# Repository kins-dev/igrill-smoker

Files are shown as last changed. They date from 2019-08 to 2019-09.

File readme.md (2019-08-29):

# Starting with Raspberry Pi Stretch 

<!-- markdownlint-disable MD036 -->
**&#x1F534; Note: You are 100% responsible for ensuring safe food practices are followed.**

**&#x1F534; Check and modify temperatures as appropriate**
<!-- markdownlint-enable MD036 -->

<!-- markdownlint-disable MD033 -->
<h2>Table of Contents</h2>
<!-- markdownlint-enable MD033 -->
<!-- markdownlint-disable MD039 -->
<!-- @import "[TOC]" {cmd="toc" depthFrom=2 depthTo=6 orderedList=false} -->

<!-- code_chunk_output -->

- [Problem Statement](#problem-statement)
- [Design](#design)
- [Equipment](#equipment)
- [Requirements](#requirements)
- [Installation](#installation)
- [Software Setup](#software-setup)
- [Using iGrill Mini](#using-igrill-mini)
- [Grill Setup](#grill-setup)
- [Running](#running)
- [Lighttpd Setup](#lighttpd-setup)
- [Project Notes](#project-notes)
- [iGrill Smoker Board Rev. *A](#igrill-smoker-board-rev-a)
  - [*A Board](#a-board)
  - [*A Notes](#a-notes)
  - [*A Parts](#a-parts)
- [iGrill Smoker Board Rev. *B](#igrill-smoker-board-rev-b)
  - [*B Board](#b-board)
  - [*B Notes](#b-notes)
  - [*B Parts](#b-parts)
- [iGrill Smoker Board Rev. *C](#igrill-smoker-board-rev-c)
  - [*C Board](#c-board)
  - [*C Notes](#c-notes)
  - [*C Parts](#c-parts)
- [iGrill Smoker Board Rev. *D](#igrill-smoker-board-rev-d)
  - [*D Notes](#d-notes)
  - [*D Parts](#d-parts)
- [iGrill Smoker Board Rev. *E](#igrill-smoker-board-rev-e)
  - [*E Notes](#e-notes)
  - [*E Parts](#e-parts)

<!-- /code_chunk_output -->

<!-- markdownlint-enable MD039 -->
## Problem Statement

Create a low cost smoking unit that can be controlled/monitored via the internet.

## Design

See the [design document](documentation/iGrill_smoker_design.md).

## Equipment

Prices as of June 10th, 2019.  Some items like the hotplates or skillet can be found at Goodwill instead.  Total cost (new) $287.96.  Every item can be used for more than one task.  Meat, wood chips, and extension cords not included.

- [Weber Grill](https://www.amazon.com/Weber-741001-Original-22-Inch-Charcoal/dp/B00004RALU/ref=sr_1_3) - $109
- [iGrill2](https://www.amazon.com/Weber-7203-iGrill-2-Thermometer/dp/B01MG2CNDL/ref=sr_1_3) - $64.99
- [Hotplate](https://www.amazon.com/Cuisine-ESB-300X-Maxi-Matic-Single-Electric/dp/B0006A2ZTS/ref=sr_1_70) - 2x @ $12.96
- [TP-Link Kasa](https://www.amazon.com/TP-Link-HS100-Required-Google-Assistant/dp/B0178IC734/ref=sr_1_4) - $14.69
- [Raspberry Pi](https://www.target.com/p/raspberry-pi-3-model-b-project-board/-/A-53349740) - $34.49
- [SD Card](https://www.amazon.com/Kingston-Digital-microSDHC-SDC4-8GBSP/dp/B0027CA7UW/ref=sr_1_11) - $3.99
- [Skillets](https://www.amazon.com/dp/B073Q8P6C8/ref=psdc_289821_t1_B00008GKDN) - 2x @ $10.93
- [8 inch rings](https://www.amazon.com/Ateco-14408-8-Inch-Stainless-Cutter/dp/B002A5BU5M/ref=pd_sbs_79_5/140-6446357-6003018) - 2x @ $6.51

## Requirements

You must have:

- Raspberry Pi 3
- TP-Link Kasa
- iGrill2 or iGrill3 (iGrill mini coming soon for time based smoking)

Optional items:

- LEDs with current limiting resistors
- Speaker with 3.5 mm stereo jack input

*Note: This has been tested using a Raspberry Pi B 3 with Raspian Stretch.  Your milage may vary.*

This guide assumes you've done the basic setup of network and updated the system on your Raspberry Pi.  Remember, you probably want to enable ssh access.  You must have your iGrill ready to complete the installation and setup.  This does require python 3 to be installed.

## Installation

Either download and run ```auto-install.sh``` from the installation directory or run the following commands:

```bash
git clone https://git.kins.dev/igrill-smoker
cd igrill-smoker/install
bash run-install.sh
```

After starting the ```run-install.sh``` script, you should turn on your iGrill v2.  Installation shouldn't take long and the device is needed for setup.

## Software Setup

Copy ```config/iGrill_config.example.ini``` to ```config/iGrill_config.ini```.  Update ```iGrill_config.ini``` with any system settings you want to change.

Here is what that file looks like:
<!-- TODO: add > at the end of this line, open MPE, and use shift enter to regenerate --
```bash {cmd hide modify_source}
echo -n \`\`\`ini
cat config/iGrill_config.example.ini
echo -n \`\`\`
```
<!---->

<!-- code_chunk_output -->

```ini
# Copyright (c) 2019:   Scott Atkins <scott@kins.dev>
#                       (https://git.kins.dev/igrill-smoker)
# License:              MIT License
#                       See the LICENSE file
[iGrill]
# can be Standard or Mini
Type=Standard

[Probes]
# For iGrill mini set food probe to 0 and smoke probe to 1

# Food probe must be set between 0 and 4, where 0 means the
# probe is disabled.  The left most probe is 1 and right most
# is 4 on the iGrill 2/3
#
# If you disable the food probe, you must use a stage that
# is iGrill mini compatible (see stage file) or disable stages
FoodProbe=1

# Smoke probe must be set between 1 and 4.  The left most probe
# is 1 and right most is 4 on the iGrill 2/3
SmokeProbe=4

[Logging]
LogLevel=INFO
LogFile=

[Kasa]
# Name of your plug in the Kasa app, case sensitive
Name=iGrill-smoker

[Smoking]
MaxTempChange=2
TempBandSize=7

# Can be the name of any file in the stages directory (excluding the .sh) or None
Food=brisket

# Only valid if Food=None
SmokeMid=225
InternalTarget=185

[Reporting]
# time in seconds between polls of the iGrill
# faster polling means more power use
PollTime=20

ResultsDirectory=/var/www/html
CSVFile=current.csv
StateFile=state.json
```

<!-- /code_chunk_output -->

Edit the chart.html file in the website_example directory to suit your needs and copy it to your ```/var/www/html``` directory.

## Using iGrill Mini

The iGrill mini has a single probe.  That means you can either monitor the smoke temperature or the food temperature.  Since this is controlling a plug for the smoke, you should not monitor the food temperature via the iGrill mini probe.  Follow the instructions in iGrill_config.example.ini for setting the probe values.

## Grill Setup

## Running

Start a smoking session by running:

```bash
./start_smoking.sh
```

## Lighttpd Setup

Secure your instance of lighttpd using the instructions at <https://github.com/galeone/letsencrypt-lighttpd/blob/master/renew.sh>.  You may want a wildcard certificate and you can find instructions via <https://asknetsec.com/generate-lets-encrypt-free-wildcard-certificate-using-certbot-ubuntu-16-04/>.  Check your SSL setup via <https://www.ssllabs.com/ssltest/index.html>.

Also, it may be a good idea to setup lighttpd such that ```*.csv```/```*.json``` is not cached.  Here's an example lighttpd config file:

```ruby
server.modules = (
        "mod_expire",
        "mod_access",
        "mod_alias",
        "mod_compress",
        "mod_redirect",
        "mod_setenv",
        "mod_dirlisting",
)

server.document-root                            = "/var/www/html"
server.upload-dirs                              = ( "/var/cache/lighttpd/uploads" )
server.errorlog                                 = "/var/log/lighttpd/error.log"
server.pid-file                                 = "/var/run/lighttpd.pid"
server.username                                 = "www-data"
server.groupname                                = "www-data"
server.port                                     = 80

index-file.names                                = ( "index.php", "index.html", "index.lighttpd.html" )
url.access-deny                                 = ( "~", ".inc" )
static-file.exclude-extensions                  = ( ".php", ".pl", ".fcgi" )

compress.cache-dir                              = "/var/cache/lighttpd/compress/"
compress.filetype                               = ( "application/javascript", "text/css", "text/html", "text/plain" )

# default listening port for IPv6 falls back to the IPv4 port
## Use ipv6 if available
#include_shell "/usr/share/lighttpd/use-ipv6.pl " + server.port
include_shell "/usr/share/lighttpd/create-mime.assign.pl"
include_shell "/usr/share/lighttpd/include-conf-enabled.pl"

# SSL Config
$SERVER["socket"] == ":443" {
        protocol                                = "https://"
        ssl.engine                              = "enable"
        ssl.ca-file                             = "/etc/lighttpd/fullchain.pem"
        ssl.pemfile                             = "/etc/lighttpd/wildcard.cert.pem"

        setenv.add-environment  = (
                "HTTPS"                         => "on"
        )

        setenv.add-response-header  = (
                # Allow cross domain access
                # Safari requires *
                "Access-Control-Allow-Origin"   => "*",

                # Used to identify the server based on headers
                "Server"                        => "Server name",

                # Set timeout for ssl access
                "Strict-Transport-Security"     => "max-age=15768000;"
        )

        # Mitigate BEAST attack:
        #
        # A stricter base cipher suite. For details see:
        # http://blog.ivanristic.com/2011/10/mitigating-the-beast-attack-on-tls.html
        ssl.cipher-list                         = "ECDHE-ECDSA-AES256-GCM-SHA384:ECDHE-RSA-AES256-GCM-SHA384:ECDHE-ECDSA-CHACHA20-POLY1305:ECDHE-RSA-CHACHA20-POLY1305:ECDHE-ECDSA-AES128-GCM-SHA256:ECDHE-RSA-AES128-GCM-SHA256:ECDHE-ECDSA-AES256-SHA384:ECDHE-RSA-AES256-SHA384:ECDHE-ECDSA-AES128-SHA256:ECDHE-RSA-AES128-SHA256"

        # Make the server prefer the order of the server side cipher suite instead of the client suite.
        # This is necessary to mitigate the BEAST attack (unless you disable all non RC4 algorithms).
        # This option is enabled by default, but only used if ssl.cipher-list is set.
        ssl.honor-cipher-order                  = "enable"

        # Mitigate CVE-2009-3555 by disabling client triggered renegotiation
        # This is enabled by default.
        ssl.disable-client-renegotiation        = "enable"
        ssl.ec-curve                            = "secp384r1"
        ssl.use-compression                     = "disable"

        # Disable SSLv2 because is insecure
        ssl.use-sslv2                           = "disable"

        # Disable SSLv3 (can break compatibility with some old browser) /cares
        ssl.use-sslv3                           = "disable"
}

# Prevent caching of json/csv files
$HTTP["url"] =~ "/.*\.(json|csv)$" {
        expire.url = (
                ""                              => "access 0 seconds",
        )
}
```

## Project Notes

1.3 Uses TP-Link Kasa for power control.  1.4 includes a brand new power control board that plugs into the Raspberry Pi which will allow much more fine grain control of the smoker temperature.

This is necessary because the relay in the TP-Link won't handle the number of on/off cycles required.  Instead a solid state relay is used.  A word of caution, this is not UL rated or certified.  If you don't know which end of the soldering iron to hold, then you probably should just stick with 1.3.

The TP-Link Kasa plug will still be used as a failsafe device in the system.

## iGrill Smoker Board Rev. *A

### *A Board

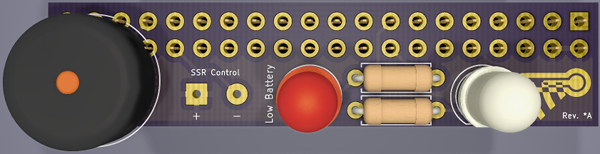
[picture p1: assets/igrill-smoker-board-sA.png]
Board Rev. *A


This board has a buzzer, two LEDs and connection points for the solid state relay.  It sits off the edge of the Raspberry Pi GPIOs.

### *A Notes

This board should not be used.

Features

- Two LEDs
- Buzzer
- Small design

Defects

- The spacing for the resistors is off
- Hard to hand solder
- Hangs off the board the wrong way
- Red LED stays on due to leakage current
- Leakage current to the SSR

### *A Parts

- Header (2x20): [DigiKey](https://www.digikey.com/product-detail/en/sullins-connector-solutions/SFH11-PBPC-D20-ST-BK/S9200-ND/1990093) $1.94
- LED (Green): [DigiKey](https://www.digikey.com/product-detail/en/lite-on-inc/LTL-4233/160-1130-ND/217580) $0.36
- LED (Red): [DigiKey](https://www.digikey.com/product-detail/en/wurth-electronics-inc/151051RS11000/732-5016-ND/4490012) $0.15
- Resistors (100 ohm x2): [DigiKey](https://www.digikey.com/product-detail/en/stackpole-electronics-inc/CF14JT100R/CF14JT100RCT-ND/1830327) $0.10
- Buzzer: [DigiKey](https://www.digikey.com/product-detail/en/tdk-corporation/PS1240P02BT/445-2525-1-ND/935930) $0.68

## iGrill Smoker Board Rev. *B

### *B Board

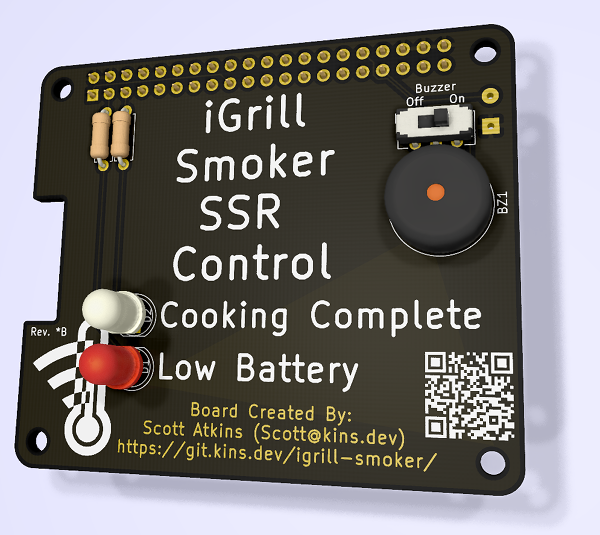
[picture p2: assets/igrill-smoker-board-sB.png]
Board Rev. *B


This board has a buzzer, two LEDs and connection points for the solid state relay.  It sits on the Raspberry Pi GPIOs.

### *B Notes

This board should not be used.

New Features

- Sits over the Pi with mounting holes
- Board auto detect works
- Buzzer switch

Defects

- The spacing for the resistors is off
- The QR code doesn't always read correctly
- The solder mask makes it hard to read the @ symbol
- Red LED stays on due to leakage current
- Buzzer makes a sound when it shouldn't
- Leakage current to the SSR

### *B Parts

- Header (2x20): [DigiKey](https://www.digikey.com/product-detail/en/sullins-connector-solutions/SFH11-PBPC-D20-ST-BK/S9200-ND/1990093) $1.94
- LED (Green): [DigiKey](https://www.digikey.com/product-detail/en/lite-on-inc/LTL-4233/160-1130-ND/217580) $0.36
- LED (Red): [DigiKey](https://www.digikey.com/product-detail/en/wurth-electronics-inc/151051RS11000/732-5016-ND/4490012) $0.15
- Resistors (100 ohm x2): [DigiKey](https://www.digikey.com/product-detail/en/stackpole-electronics-inc/CF14JT100R/CF14JT100RCT-ND/1830327) $0.10
- Buzzer: [DigiKey](https://www.digikey.com/product-detail/en/tdk-corporation/PS1240P02BT/445-2525-1-ND/935930) $0.68
- Switch: [DigiKey](https://www.digikey.com/product-detail/en/c-k-components/JS202011CQN/401-2001-ND/1640097) $0.43

## iGrill Smoker Board Rev. *C

### *C Board

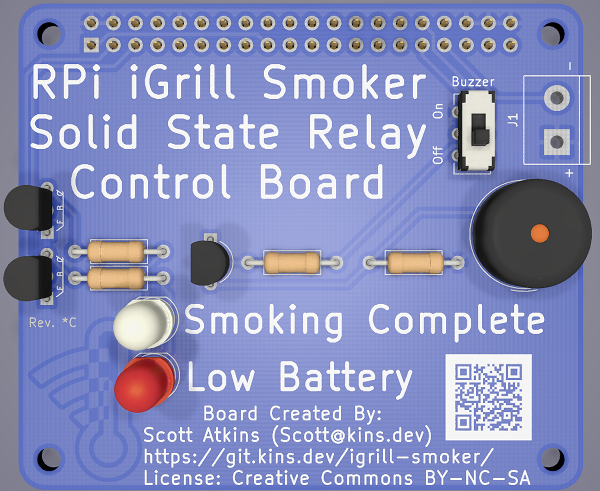
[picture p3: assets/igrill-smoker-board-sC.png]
Board Rev. *C


This board has a buzzer, two LEDs and a terminal block for the solid state relay.  It sits on the Raspberry Pi GPIOs.

### *C Notes

This board is currently in production and has not been tested.

New Features

- NPN transistors to remove leakage

Fixes

- QR Code
- Resistor spacing
- Solder mask changed to silk screen for fine pitch
- Using suggested design for the buzzer

Defects

- Leakage current to the SSR
- Missing resistors on NPN transistor base (good design practice)

### *C Parts

- Header (2x20): [DigiKey](https://www.digikey.com/product-detail/en/sullins-connector-solutions/SFH11-PBPC-D20-ST-BK/S9200-ND/1990093) $1.94
- LED (Green): [DigiKey](https://www.digikey.com/product-detail/en/lite-on-inc/LTL-4233/160-1130-ND/217580) $0.36
- LED (Red): [DigiKey](https://www.digikey.com/product-detail/en/wurth-electronics-inc/151051RS11000/732-5016-ND/4490012) $0.15
- Resistors (100 ohm x3): [DigiKey](https://www.digikey.com/product-detail/en/stackpole-electronics-inc/CF14JT100R/CF14JT100RCT-ND/1830327) $0.10
- Buzzer: [DigiKey](https://www.digikey.com/product-detail/en/tdk-corporation/PS1240P02BT/445-2525-1-ND/935930) $0.68
- Switch: [DigiKey](https://www.digikey.com/product-detail/en/c-k-components/JS202011CQN/401-2001-ND/1640097) $0.43
- Transistors (NPN x3): [DigiKey](https://www.digikey.com/product-detail/en/micro-commercial-co/2N3904-AP/2N3904-APCT-ND/950591) $0.19

## iGrill Smoker Board Rev. *D

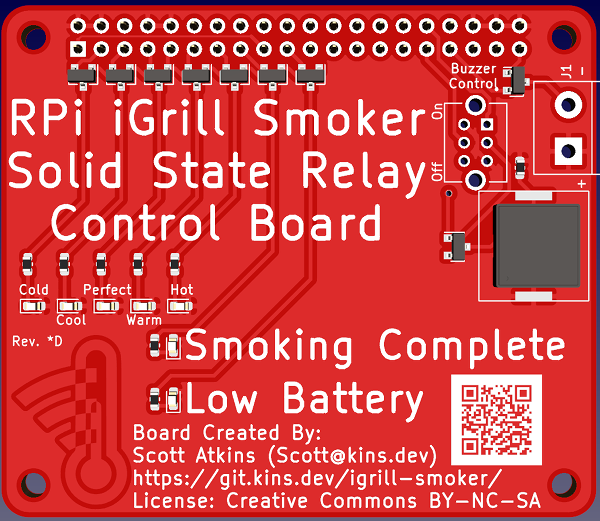
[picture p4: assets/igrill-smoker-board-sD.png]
Board Rev. *D


This board has a buzzer, seven LEDs and connection points for the solid state relay.  It sits on the Raspberry Pi GPIOs.

### *D Notes

The boards back from production are bad

New Features

- Five new LEDs for temperature monitoring
- Surface mount parts
- Mosfet transistors so a resistor is no longer needed
- Transistor to prevent SSR leakage
- Cheaper parts

Defects

- Silk screen issue
- QR Code issue (too small, inverted on back)
- Transistors wired backwards

### *D Parts

TODO: Add part list

## iGrill Smoker Board Rev. *E

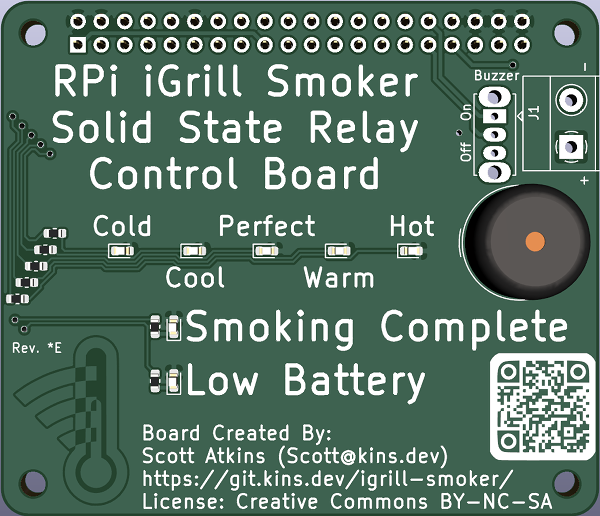
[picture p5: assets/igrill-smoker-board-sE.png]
Board Rev. *E


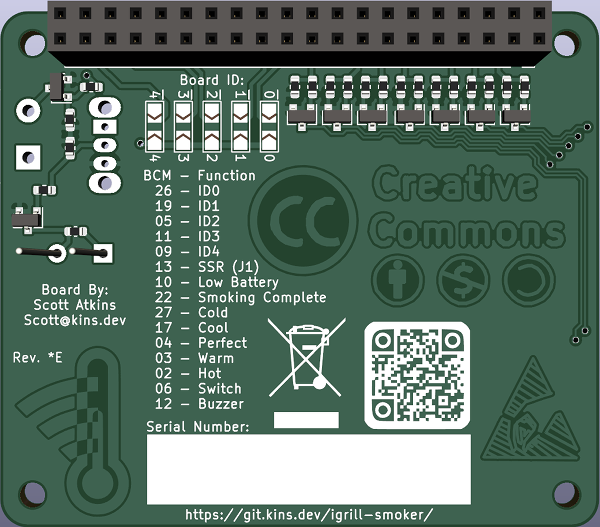
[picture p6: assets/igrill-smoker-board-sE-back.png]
Board Rev. *E back


This board has a buzzer, seven LEDs and connection points for the solid state relay.  It sits on the Raspberry Pi GPIOs.  It also has jumpers for a board id number

### *E Notes

This board is not yet in production and has not been tested.

New Features

- New QR code
- Pull down resistors for all transistors

Defects

- None found yet

### *E Parts

TODO: Add part list

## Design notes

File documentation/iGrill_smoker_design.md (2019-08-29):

# iGrill Smoker Design

Copyright &copy; 2019 Scott Atkins
<!-- markdownlint-disable MD033 -->
<h2>Table of Contents</h2>
<!-- markdownlint-enable MD033 -->
<!-- markdownlint-disable MD007 -->
<!-- markdownlint-disable MD010 -->
<!-- markdownlint-disable MD039 -->
<!-- @import "[TOC]" {cmd="toc" depthFrom=2 depthTo=6 orderedList=false} -->

<!-- code_chunk_output -->

- [Introduction](#introduction)
- [Sources](#sources)
- [Files](#files)
  - [Bash](#bash)
  - [Python](#python)
  - [INI](#ini)
  - [JSON](#json)
  - [CSV](#csv)
- [File relation graph](#file-relation-graph)
  - [/start_smoking.sh](#start_smokingsh)
  - [/scripts/config.sh](#scriptsconfigsh)
  - [/scripts/monitor.py](#scriptsmonitorpy)
  - [/scripts/data.sh](#scriptsdatash)
- [Configuration](#configuration)
  - [INI File](#ini-file)
- [How to Generate a Smoke Schedule](#how-to-generate-a-smoke-schedule)

<!-- /code_chunk_output -->
<!-- markdownlint-enable MD007 -->
<!-- markdownlint-enable MD010 -->
<!-- markdownlint-enable MD039 -->
## Introduction

There are a lot of moving parts in this project, so this is an attempt to document those parts and how they interact.  Additionally this a moving target, so some information can be out of date.

## Sources

Like most projects this has come from a number of different sources.

- [Github iGrill](https://github.com/kvantetore/igrill)
- [Bash ini Parser](https://github.com/rudimeier/bash_ini_parser)
- [Path helper](https://stackoverflow.com/questions/59895/get-the-source-directory-of-a-bash-script-from-within-the-script-itself)
- [Highcharts](https://www.highcharts.com/)
- [tplink-smarthome-api](https://www.npmjs.com/package/tplink-smarthome-api)

## Files

This is an attempt to document all the files in the project.  Relations between files is shown [below](#file-relation-graph).

### Bash

- **[igrill-smoker/start_smoking.sh](../start_smoking.sh)** - The main script to start a smoking session.
  - Loads [paths.sh](../scripts/utils/paths.sh)
  - Loads [leds.sh](../scripts/utils/leds.sh)
  - Loads [kasa.sh](../scripts/utils/kasa.sh)
  - Loads [limits.sh](../scripts/utils/limits.sh)
  - Loads [config.sh](../scripts/config.sh)
  - Cleans up after the last run
  - Resets the limits
  - Resets the LEDs
  - Finds iGrill device if needed
  - Creates list of CSV files
  - Creates new CSV file and links it to current.csv
  - Stats [scripts/py_utils/kasa_daemon.py](../scripts/py_utils/kasa_daemon.py) to control the plug state
  - Resets the BT device on the Raspberry Pi
  - Calls [scripts/monitor.py](../scripts/monitor.py) to capture data over bluetooth
  - On Exit
    - Uses [scripts/py_utils/kasa_client.py](../scripts/py_utils/kasa_client.py) to stop [scripts/py_utils/kasa_daemon.py](../scripts/py_utils/kasa_daemon.py)
    - Cleans up run files
    - Resets the LEDs
- **[igrill-smoker/scripts/config.sh](../scripts/config.sh)** - Loads configuration
  - Loads [read_ini.sh](../scripts/utils/read_ini.sh)
  - Loads [defaults.sh](../scripts/utils/defaults.sh)
  - Loads [food script](../config/stage/)
- **[igrill-smoker/scripts/data.sh](../scripts/data.sh)** - Handles temperature data
  - Loads [paths.sh](../scripts/utils/paths.sh)
  - Loads [config.sh](../scripts/config.sh)
  - Determines if it is time to load the next stage
    - If so writes stage.sh and reloads [config.sh](../scripts/config.sh)
  - Reads last_temp.sh
  - Adjusts LEDs based on stage, temperature, and battery
  - Plays sounds based on stage, temperature, and battery
  - Sets the plug state based on history and current temperature
  - Writes state.json
  - Writes last_temp.sh
  - Writes data to current.csv
  - Calls to [scripts/pygrill/kasa/kasa_client.py](../scripts/pygrill/kasa/kasa_client.py) to get the plug state
  - Calls to [scripts/pygrill/board/ssrc_client.py](../scripts/pygrill/board/ssrc_client.py) to adjust the solid state relay
  - Calls to [scripts/pygrill/board/buzzer_client.py](../scripts/pygrill/board/buzzer_client.py) to sound alarms
  - Calls to [scripts/pygrill/board/leds.py](../scripts/pygrill/board/leds.py) to set the LEDs
- **[igrill-smoker/scripts/utils/bt.sh](../scripts/utils/bt.sh)** - Bluetooth functions
  - **BtReset** - Resets Bluetooth
- **[igrill-smoker/scripts/utils/create_vars.sh](../scripts/utils/create_vars.sh)** - Setup default values
  - Reads iGrill_config.example.ini
  - Creates default.sh
- **[igrill-smoker/scripts/utils/defaults.sh](../scripts/utils/defaults.sh)** - Config default values if iGrill_config.ini does not exist
- **[igrill-smoker/scripts/utils/gen_json.sh](../scripts/utils/gen_json.sh)** - Creates JSON file for Website
  - Loads [paths.sh](../scripts/utils/paths.sh)
  - Finds all CSV files that match the date format
  - Writes a JSON file with the list of files
- **[igrill-smoker/scripts/utils/get_mac.sh](../scripts/utils/get_mac.sh)** - Creates mac_config.py based on iGrill Bluetooth address
  - Loads [bt.sh](../scripts/utils/bt.sh)
  - Calls BtReset
  - Starts a scan for iGrill
    - Scan is killed when iGrill is found
  - Writes mac_config.py
  - Calls BtReset
- **[igrill-smoker/scripts/utils/limits.sh](../scripts/utils/limits.sh)** - Sets upper and lower limits for the iGrill
  - Loads [paths.sh](../scripts/utils/paths.sh)
  - Reset limits - Sets limits for all 4 probes to be -32768 to 32767
  - SetLimits - Sets limits for a particular probe
  - PrintLimits - Output set limits in an INI format
  - WriteLimits - Uses PrintLimits to write to a file
- **[igrill-smoker/scripts/utils/paths.sh](../scripts/utils/paths.sh)** - Sets up standard path variables
- **[igrill-smoker/scripts/utils/read_ini.sh](../scripts/utils/read_ini.sh)** - Reads ini file
  - read_ini - Reads the specified file and sets variables
- **igrill-smoker/run/stage.sh** - Tracks the current cooking stage
- **igrill-smoker/run/last_temp.sh** - Tracks the last temperature
- **[igrill-smoker/tests/board/board_checkout.sh](../tests/board/board_checkout.sh)** - Runs through a set of tests to check the board is functioning properly
  - LEDs
  - Buzzer

### Python

- **[igrill-smoker/scripts/pygrill/bt_monitor.py](../scripts/pygrill/bt_monitor.py)** - Top level python script
  - Loads the configuration
  - Formats the results
  - Calls [scripts/data.sh](../scripts/data.sh) with the temperature data
- **[igrill-smoker/scripts/pygrill/bluetooth/igrill.py](../scripts/pygrill/bluetooth/igrill.py)** - Interface to iGrill
  - Performs handshake
  - Grabs temperature/battery data
  - Sets probe limits
- **[igrill-smoker/scripts/pygrill/common/local_logging.py](../scripts/pygrill/common/local_logging.py)** - Sets up logging
  - Report specific log level
  - Redirects to file if specified
- **[igrill-smoker/scripts/pygrill/common/constant.py](../scripts/pygrill/common/constant.py)** - Various constants
- **[igrill-smoker/scripts/pygrill/board/board.py](../scripts/pygrill/board/board.py)** - Detects the board type
  - Cannot detect **, *A or *D.1
- **[igrill-smoker/scripts/pygrill/board/buzzer_daemon.py](../scripts/pygrill/board/buzzer_daemon.py)** - Controls the buzzer
  - plays different sounds for smoking complete and low battery
- **[igrill-smoker/scripts/pygrill/board/buzzer_client.py](../scripts/pygrill/board/buzzer_client.py)** - Passes commands to the daemon
  - done or low_battery for those tones
  - Tells the daemon to exit
- **[igrill-smoker/scripts/pygrill/kasa/kasa_daemon.py](../scripts/pygrill/kasa/kasa_daemon.py)** - Controls kasa hardware
  - Find plug by name
  - Return plug status
  - Sets countdown timer for 10 minutes when turning the plug on
- **[igrill-smoker/scripts/pygrill/kasa/kasa_client.py](../scripts/pygrill/kasa/kasa_client.py)** - Passes commands to the daemon
  - Turn plug on and off
  - Return plug status
  - Tells the daemon to exit
- **[igrill-smoker/scripts/pygrill/board/ssrc_daemon.py](../scripts/pygrill/board/ssrc_daemon.py)** - Controls solid state relay
  - Minimum is 30% max is 85%
  - Step up by 5% or 0.25%
  - Step down by 1% or 20%
  - Sets countdown timer for 10 minutes
  - On exit, kill Kasa daemon
- **[igrill-smoker/scripts/pygrill/board/ssrc_client.py](../scripts/pygrill/board/ssrc_client.py)** - Passes commands to the daemon
  - Turn up or down, a large or small amount
  - Leave everything the same, but reset the countdown
  - Tells the daemon to exit
- **[igrill-smoker/scripts/pygrill/board/leds.py](../scripts/pygrill/board/leds.py)** - Controls LEDs
  - Sets smoking complete or low battery
  - Sets temperature state:
    - Cold: low outside of band
    - Cool: low in band
    - Perfect: at target temperature
    - Warm: high in band
    - Hot: high out of band
- **igrill-smoker/scripts/pygrill/config/mac_config.py** - Mac address for the iGrill

### INI

- **[iGrill_config.ini](../config/iGrill_config.example.ini)** - Main configuration
- **limits.ini** - iGrill upper and lower limits for alarm

### JSON

- **state.json** - Current state of the smoking for website processing
- **items.json** - A list of csv files which can put into highcharts

### CSV

- **current.csv** - The current data set

## File relation graph

This is broken down into multiple graphs so it is easier to follow.

- Dotted lines are file reads/writes
- Bold lines are system calls to execute a script
- Normal lines are standard includes

### /start_smoking.sh

start_smoking

### /scripts/config.sh

config

### /scripts/monitor.py

monitor

### /scripts/data.sh

data

## Configuration

### INI File

The ini file is a one place for the user to configure this project.

<!-- NOTE: Add > at the end of this line and open markdown preview enhanced window.  Use shift enter to regenerate. --
```bash {cmd hide modify_source}
echo -n \`\`\`ini
cat ../config/iGrill_config.example.ini
```
<!-- -->
<!-- code_chunk_output -->

```ini
# Copyright (c) 2019:   Scott Atkins <scott@kins.dev>
#                       (https://git.kins.dev/igrill-smoker)
# License:              MIT License
#                       See the LICENSE file
[iGrill]
# can be Standard or Mini
Type=Standard

[Probes]
# For iGrill mini set food probe to 0 and smoke probe to 1

# Food probe must be set between 0 and 4, where 0 means the
# probe is disabled.  The left most probe is 1 and right most
# is 4 on the iGrill 2/3
#
# If you disable the food probe, you must use a stage that
# is iGrill mini compatible (see stage file) or disable stages
FoodProbe=1

# Smoke probe must be set between 1 and 4.  The left most probe
# is 1 and right most is 4 on the iGrill 2/3
SmokeProbe=4

[Logging]
LogLevel=INFO
LogFile=

[Kasa]
# Name of your plug in the Kasa app, case sensitive
Name=iGrill-smoker

[Smoking]
MaxTempChange=2
TempBandSize=7

# Can be the name of any file in the stages directory (excluding the .sh) or None
Food=brisket

# Only valid if Food=None
SmokeMid=225
InternalTarget=185

# Used to specify the solid state relay board
[SSR]
# Possible values:
#  **, *A, *B, *C, *D, *D.1, *E, Auto, None
Board=Auto

[Reporting]
# time in seconds between polls of the iGrill
# faster polling means more power use
PollTime=20

ResultsDirectory=/var/www/html
CSVFile=current.csv
StateFile=state.json

```
<!-- /code_chunk_output -->

## How to Generate a Smoke Schedule

Easiest way is to copy then edit an existing schedule.  Examples and variable description is below.

Here is what **[igrill-smoker/config/stages/brisket.py](../config/stages/brisket.py)** looks like:
<!-- NOTE: Add > at the end of this line and open markdown preview enhanced window.  Use shift enter to regenerate. --
```bash {cmd hide modify_source}
echo \`\`\`bash
cat ../config/stages/brisket.sh
echo ""
echo -n \`\`\`
```
<!-- -->
<!-- code_chunk_output -->

```bash
#!/bin/bash
# Copyright (c) 2019:   Scott Atkins <scott@kins.dev>
#                       (https://git.kins.dev/igrill-smoker)
# License:              MIT License
#                       See the LICENSE file
# Defining variables for other scripts
# shellcheck disable=2034
true
# shellcheck disable=2086
set -$-ue${DEBUG+xv}

MINI_COMPATIBLE=false

# Note: for this to work. Internal temp must be increased at each stage
# the system will go to the next stage when the food hits the designated
# internal temp

case "$STAGE" in
    1)
        # Warmup stage, keep plate at a cooler temp and limit temp rise
        STAGE_NAME="Warmup"
        SMOKE_MID=180
        MAX_TEMP_CHANGE=2
        INTERNAL_TEMP=70
    ;;
    2)
        # Smoke stage, keep plate at cooler temp, but allow bigger temp rise
        STAGE_NAME="Smoke"
        SMOKE_MID=180
        MAX_TEMP_CHANGE=2
        INTERNAL_TEMP=120
    ;;
    3)
        # Cook stage, move hotplate to higher temp, allow bigger temp rise
        STAGE_NAME="Cook"
        SMOKE_MID=225
        MAX_TEMP_CHANGE=2
        INTERNAL_TEMP=170
    ;;
    4)
        # Braise stage, move hotplate to higher temp, allow bigger temp rise
        STAGE_NAME="Braise"
        SMOKE_MID=225
        MAX_TEMP_CHANGE=2
        INTERNAL_TEMP=185
    ;;
    5|6)
        # Keep warm stage, move hotplate to higher temp, allow bigger temp rise
        STAGE_NAME="Keep warm"
        SMOKE_MID=160
        MAX_TEMP_CHANGE=2
        INTERNAL_TEMP=190
        # signal we're done
        FD_DONE=1
        # Stay in this stage
        STAGE=5
    ;;
    *)
        echo "error: unknown stage"
        exit 1
    ;;
esac
```

<!-- /code_chunk_output -->

- ```$STAGE``` - Current stage as an integer
  - Must start at 1
  - Case statement for the last stage (5 in the example) must also include last stage + 1 (eg. ```5|6```)
  - Last stage must set ```$STAGE``` to the last stage again in case it was incremented (eg. ```STAGE=5```)
- ```$STAGE_NAME``` - Name to show on the webpage for this stage
- ```$INTERNAL_TEMP``` - Target food temperature for this stage
  - Should be monotonically increasing for every stage except the last one
  - Use of ```$INTERNAL_TEMP``` means ```$MINI_COMPATIBLE``` should be false
- ```$SMOKE_MID``` - Temperature the smoke should be kept at
- ```$FD_DONE```- The value ```1``` indicates the food is done (set on the last stage)
- ```$MAX_TEMP_CHANGE``` - Maximum change over a time period.  Should be 2-4

Here is what **[igrill-smoker/config/stages/baby-back-ribs.py](../config/stages/baby-back-ribs.py)** looks like:

<!-- NOTE: Add > at the end of this line and open markdown preview enhanced window.  Use shift enter to regenerate. --
```bash {cmd hide modify_source}
echo \`\`\`bash
cat ../config/stages/baby-back-ribs.sh
echo ""
echo -n \`\`\`
```

<!-- code_chunk_output -->

```bash
#!/bin/bash
# Copyright (c) 2019:   Scott Atkins <scott@kins.dev>
#                       (https://git.kins.dev/igrill-smoker)
# License:              MIT License
#                       See the LICENSE file
# Defining variables for other scripts
# shellcheck disable=2034
true
# shellcheck disable=2086
set -$-ue${DEBUG+xv}

MINI_COMPATIBLE=true

case "$STAGE" in
    1)
        # Warmup stage, keep plate at a cooler temp
        STAGE_NAME="Warmup"
        SMOKE_MID=180
        MAX_TEMP_CHANGE=2
        TIME=15
    ;;
    2)
        # Smoke stage, keep plate at cooler temp
        STAGE_NAME="Smoke"
        SMOKE_MID=180
        MAX_TEMP_CHANGE=2
        TIME=180
    ;;
    3)
        # Cook stage, move hotplate to higher temp
        STAGE_NAME="Cook"
        SMOKE_MID=225
        MAX_TEMP_CHANGE=2
        TIME=120
    ;;
    4)
        # Sauce stage
        STAGE_NAME="Sauce"
        SMOKE_MID=225
        MAX_TEMP_CHANGE=2
        TIME=60
    ;;
    5|6)
        # Keep warm stage, move hotplate to lower temp
        STAGE_NAME="Keep warm"
        SMOKE_MID=165
        MAX_TEMP_CHANGE=2
        TIME=100
        # signal we're done
        FD_DONE=1
        # Stay in this stage
        STAGE=5
    ;;
    *)
        echo "error: unknown stage"
        exit 1
    ;;
esac
```

<!-- /code_chunk_output -->

This is iGrill mini compatible and uses the time instead of food temperature

- ```$TIME``` - Minutes to stay in this stage

Both ```$TIME``` and ```$INTERNAL_TEMP``` can be used in a stage, first event to occur moves the system to the next stage.

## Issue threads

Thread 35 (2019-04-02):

Fail in a Safe Way

kins-dev, 2019-04-02:
Turn off the plug if there's no process running.

kins-dev, 2019-04-02:
When turning the plug on, set a timer for run time:
```bash
tplink-smarthome-api send $IP '{"count_down":{"delete_all_rules":{}}}}'
tplink-smarthome-api send $IP '{"count_down":{"add_rule":{"enable":1,"delay":300,"act":0,"name":"turn of"}}}'
```

Closed 2019-04-03.

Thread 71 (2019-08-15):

SSRC Unittests

kins-dev, 2019-08-15:
Solid state relay control needs unittests.  Should use python mock to check that it is called with the correct numbers.

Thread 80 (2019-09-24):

Smoker is Too Cold

kins-dev, 2019-09-24:
With the Kingsford grill I cannot hit 225° F with a single hot plate.  A single SSR won't handle the current of multiple hot plates.  The system needs to handle these issues.

Option 1:
Change heating mechanism

Option 2:
Setup with multiple SSRs

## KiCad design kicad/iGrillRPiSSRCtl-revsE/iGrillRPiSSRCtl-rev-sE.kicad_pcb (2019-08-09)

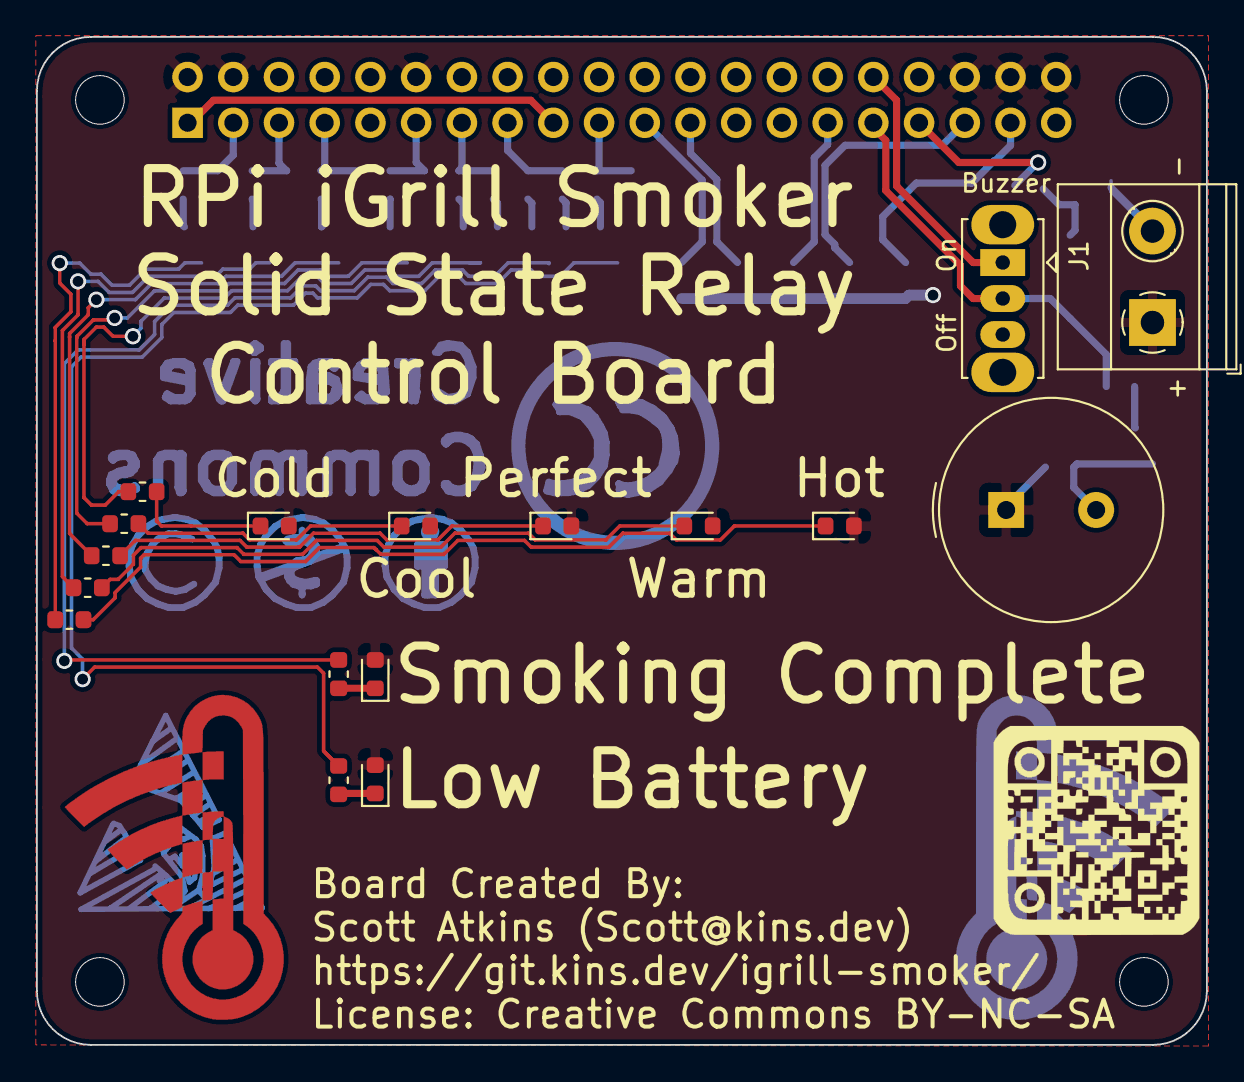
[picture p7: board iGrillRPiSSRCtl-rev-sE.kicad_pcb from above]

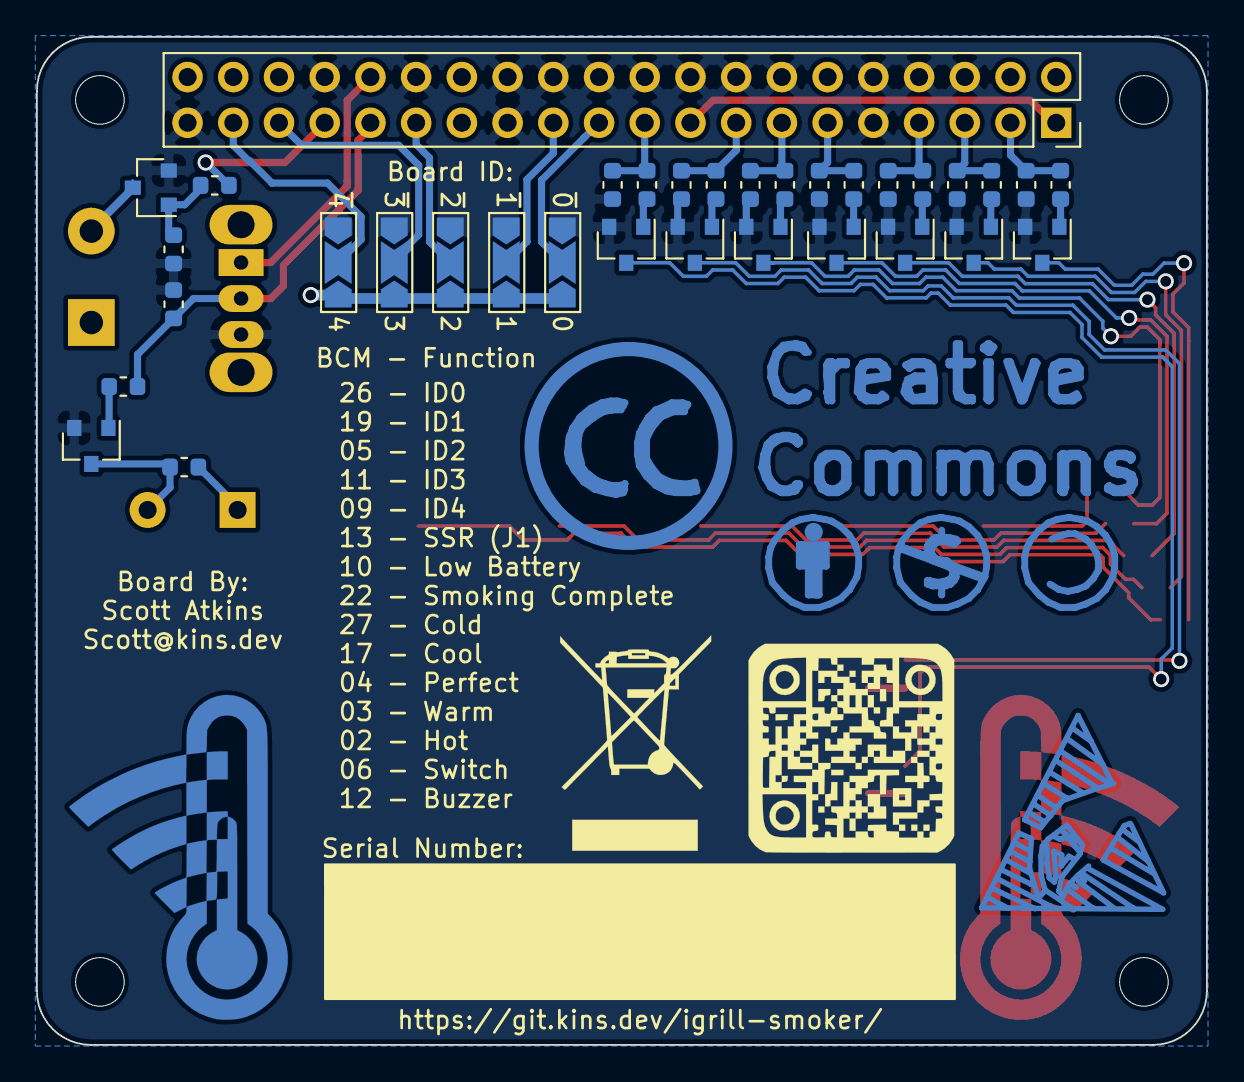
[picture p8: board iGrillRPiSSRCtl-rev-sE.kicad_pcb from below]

Board: 2 copper layers, 65.0 x 56.0 mm, 55 parts (34 on the bottom side), 43 nets.

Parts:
BZ1: Buzzer; Buzzer_TDK_PS1240P02BT_D12.2mm_H6.5mm
D1: Low Battery; LED_0603_1608Metric
D2: Smoking Complete; LED_0603_1608Metric
D3: Cold; LED_0603_1608Metric
D4: Cool; LED_0603_1608Metric
D5: Perfect; LED_0603_1608Metric
D6: Warm; LED_0603_1608Metric
D7: Hot; LED_0603_1608Metric
J1: Screw_Terminal_01x02; TerminalBlock_Phoenix_MKDS-1,5-2-5.08_1x02_P5.08mm_Horizont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
JP1, JP2, JP3, JP4, JP5: Jumper_3_Open; SolderJumper-3_P2.0mm_Open_TrianglePad1.0x1.5mm_NumberLabels
MK1, MK2, MK3, MK4: M2.5; MountingHole_2.7mm_M2.5
P1: Conn_02x20_Odd_Even; PinSocket_2x20_P2.54mm_Vertical
Q1, Q2, Q3, Q4, Q5, Q6, Q7, Q8, Q9: MMBT3904LT1G; SOT-23
R1, R3, R5, R7, R9, R12, R14: 180Ω; R_0603_1608Metric
R2, R4, R6, R8, R10, R11, R13, R15, R16, R17: 1kΩ; R_0603_1608Metric
R18, R19, R20, R21, R22, R23, R24, R25, R26: 10kΩ; R_0603_1608Metric
SW1: SW_SPDT; SW_Slide_1P2T_CK_OS102011MS2Q

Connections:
+3V3: P1.1, P1.17
+5V: BZ1.1, D1.2, D2.2, D3.2, D4.2, D5.2, D6.2, D7.2, J1.1, JP1.3, JP2.3, JP3.3, JP4.3, JP5.3, P1.2, P1.4, P1.12, P1.36, P1.38, P1.40, R17.1
/GPIO2(SDA1): P1.3, R15.2, R25.1
/GPIO3(SCL1): P1.5, R13.2, R24.1
/GPIO4(GCLK): P1.7, R10.2, R23.1
/GPIO5: JP3.2, P1.29
/GPIO6: P1.31, R16.1, R26.2, SW1.2
/GPIO9(SPI0_MISO): JP1.2, P1.21
/GPIO10(SPI0_MOSI): P1.19, R2.2, R18.1
/GPIO11(SPI0_SCK): JP2.2, P1.23
/GPIO12(PWM0): P1.32, SW1.1
/GPIO13(PWM1): P1.33, R11.1
/GPIO17(GEN0): P1.11, R8.2, R21.1
/GPIO19(SPI1_MISO): JP4.2, P1.35
/GPIO22(GEN3): P1.15, R4.2, R19.1
/GPIO26: JP5.2, P1.37
/GPIO27(GEN2): P1.13, R6.2, R20.1
GND: JP1.1, JP2.1, JP3.1, JP4.1, JP5.1, P1.6, P1.8, P1.9, P1.10, P1.14, P1.16, P1.18, P1.20, P1.22, P1.24, P1.25, P1.26, P1.30, P1.34, P1.39, Q1.2, Q2.2, Q3.2, Q4.2, Q5.2, Q6.2, Q7.2, Q8.2, Q9.2, R18.2, R19.2, R20.2, R21.2, R22.1, R23.2, R24.2, R25.2, R26.1, SW1.3
unnamed: BZ1.2, Q9.3, R17.2
unnamed: D1.1, R1.1
unnamed: D2.1, R3.1
unnamed: D3.1, R5.1
unnamed: D4.1, R7.1
unnamed: D5.1, R9.1
unnamed: D6.1, R12.1
unnamed: D7.1, R14.1
unnamed: J1.2, Q6.3
unnamed: Q1.1, R2.1
unnamed: Q1.3, R1.2
unnamed: Q2.1, R4.1
unnamed: Q2.3, R3.2
unnamed: Q3.1, R6.1
unnamed: Q3.3, R5.2
unnamed: Q4.1, R8.1
unnamed: Q4.3, R7.2
unnamed: Q5.1, R10.1
unnamed: Q5.3, R9.2
unnamed: Q6.1, R11.2, R22.2
unnamed: Q7.1, R13.1
unnamed: Q7.3, R12.2
unnamed: Q8.1, R15.1
unnamed: Q8.3, R14.2
unnamed: Q9.1, R16.2

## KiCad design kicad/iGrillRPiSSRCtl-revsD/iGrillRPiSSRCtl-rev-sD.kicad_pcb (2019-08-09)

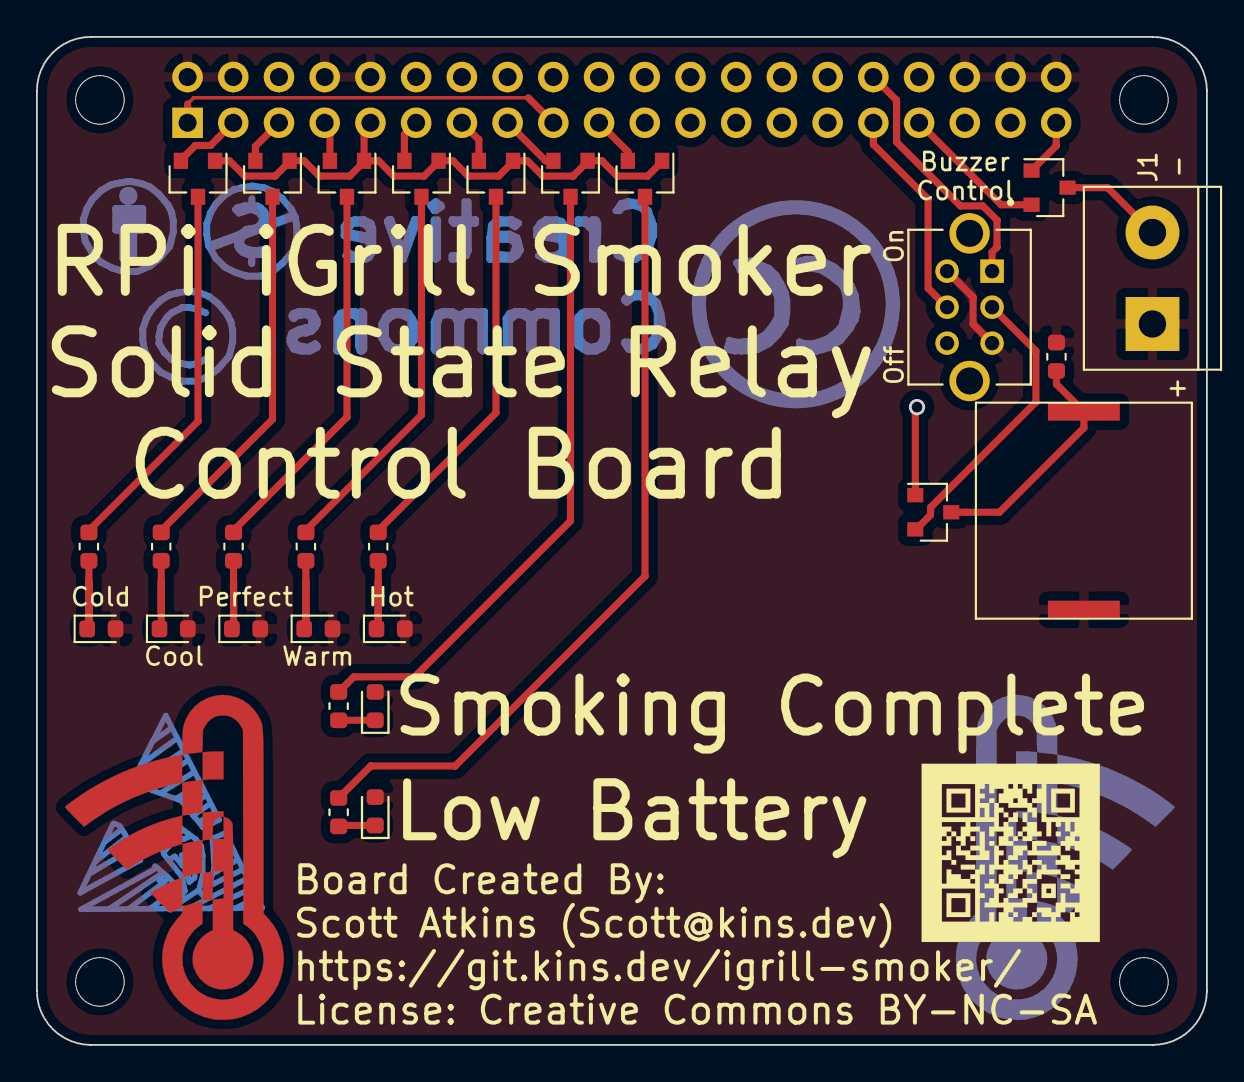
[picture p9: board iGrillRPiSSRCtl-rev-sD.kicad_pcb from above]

Board: 2 copper layers, 65.0 x 56.0 mm, 32 parts (1 on the bottom side), 30 nets.

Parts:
BZ1: Buzzer; Buzzer_KELIKING_KLJ-1230-smd
D1: Low Battery; LED_0603_1608Metric
D2: Smoking Complete; LED_0603_1608Metric
D3: Hot; LED_0603_1608Metric
D4: Warm; LED_0603_1608Metric
D5: Perfect; LED_0603_1608Metric
D6: Cool; LED_0603_1608Metric
D7: Cold; LED_0603_1608Metric
J1: Screw_Terminal_01x02; TerminalBlock_bornier-2_P5.08mm
MK1, MK2, MK3, MK4: M2.5; MountingHole_2.7mm_M2.5
P1: Conn_02x20_Odd_Even; PinSocket_2x20_P2.54mm_Vertical
Q1, Q2, Q3, Q4, Q5, Q6, Q7, Q8, Q9: Q_NPN_ECB; SOT-23
R1, R5, R6, R8, R9: 120Ω; R_0603_1608Metric
R2, R7: 82Ω; R_0603_1608Metric
R4: 1kΩ; R_0603_1608Metric
SW1: Off On; SW_OS202011MS2QS1

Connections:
+3V3: P1.1, P1.17
+5V: BZ1.1, D1.2, D2.2, D3.2, D4.2, D5.2, D6.2, D7.2, J1.1, P1.2, P1.4, P1.8, P1.10, P1.36, P1.38, P1.40, R4.1, SW1.3, SW1.4
/GPIO2(SDA1): P1.3, Q8.2
/GPIO3(SCL1): P1.5, Q7.2
/GPIO4(GCLK): P1.7, Q6.2
/GPIO6: P1.31, SW1.5
/GPIO10(SPI0_MOSI): P1.19, Q2.2
/GPIO12(PWM0): P1.32, SW1.1
/GPIO13(PWM1): P1.33, Q9.2
/GPIO17(GEN0): P1.11, Q5.2
/GPIO22(GEN3): P1.15, Q3.2
/GPIO27(GEN2): P1.13, Q4.2
GND: P1.6, P1.9, P1.12, P1.14, P1.16, P1.18, P1.20, P1.22, P1.24, P1.25, P1.26, P1.30, P1.34, P1.39, Q1.1, Q2.1, Q3.1, Q4.1, Q5.1, Q6.1, Q7.1, Q8.1, Q9.1, SW1.6
unnamed: BZ1.2, Q1.3, R4.2
unnamed: D1.1, R1.1
unnamed: D2.1, R2.1
unnamed: D3.1, R5.1
unnamed: D4.1, R6.1
unnamed: D5.1, R7.1
unnamed: D6.1, R8.1
unnamed: D7.1, R9.1
unnamed: J1.2, Q9.3
unnamed: Q1.2, SW1.2
unnamed: Q2.3, R1.2
unnamed: Q3.3, R2.2
unnamed: Q4.3, R5.2
unnamed: Q5.3, R6.2
unnamed: Q6.3, R7.2
unnamed: Q7.3, R8.2
unnamed: Q8.3, R9.2

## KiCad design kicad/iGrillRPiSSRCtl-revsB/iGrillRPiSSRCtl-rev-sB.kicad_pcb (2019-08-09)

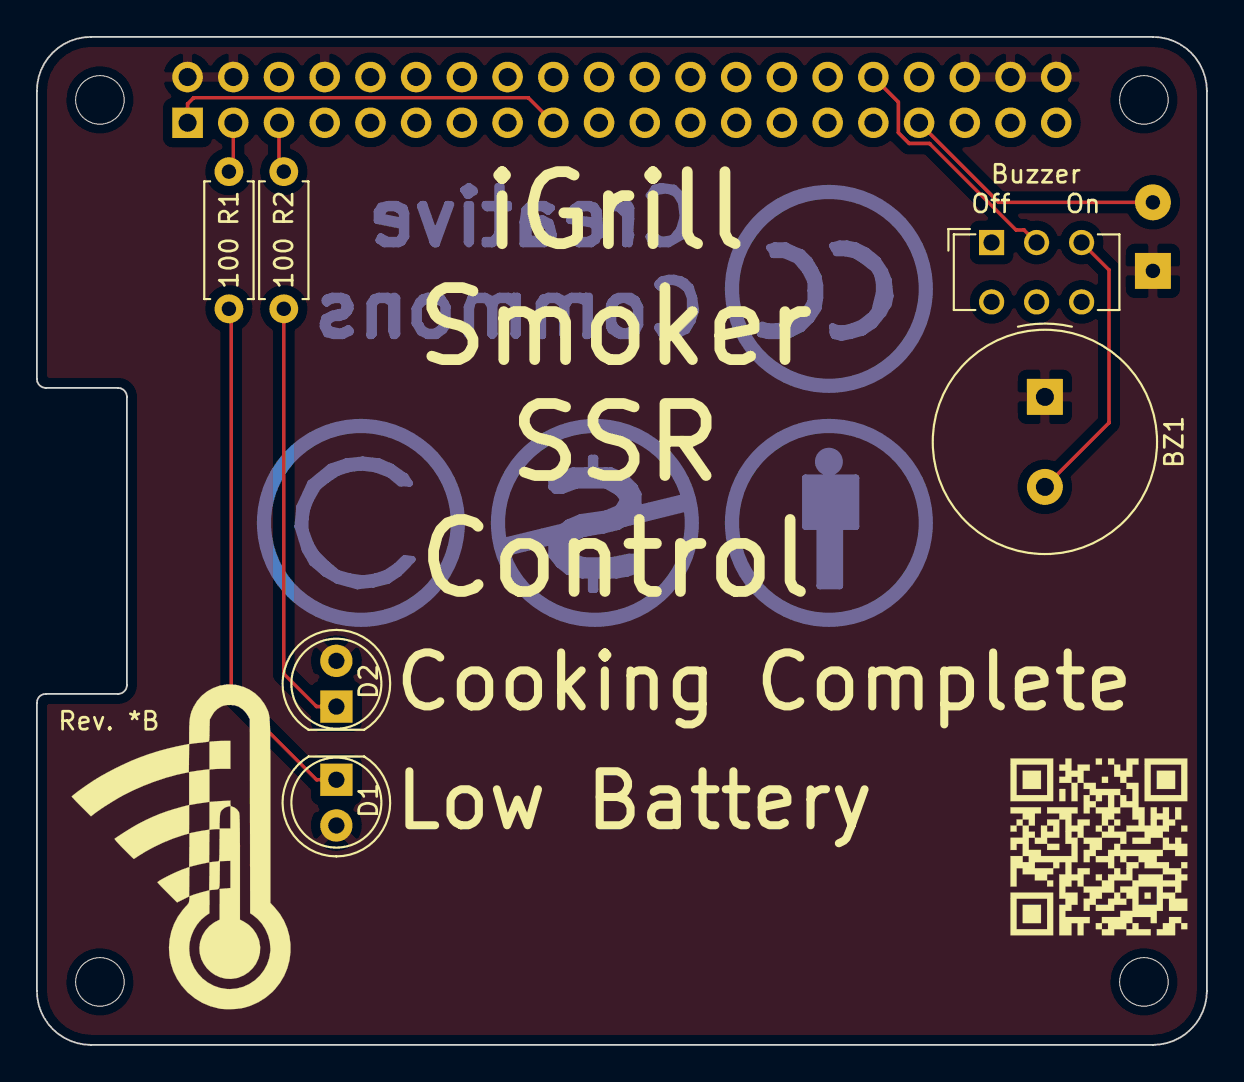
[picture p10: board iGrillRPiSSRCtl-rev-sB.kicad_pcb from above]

Board: 2 copper layers, 65.0 x 56.0 mm, 12 parts (1 on the bottom side), 10 nets.

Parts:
BZ1: Buzzer; Buzzer_TDK_PS1240P02BT_D12.2mm_H6.5mm
D1: Low Battery; LED_D5.0mm
D2: Cooking Complete; LED_D5.0mm_Clear
J1: Conn_01x02; SolderWirePad_1x02_P3.81mm_Drill0.8mm
MK1, MK2, MK3, MK4: M2.5; MountingHole_2.7mm_M2.5
Off    On: SW_DPDT_x2; SW_CuK_JS202011CQN_DPDT_Straight
P1: Conn_02x20_Odd_Even; PinSocket_2x20_P2.54mm_Vertical
R1, R2: 100; R_Axial_DIN0207_L6.3mm_D2.5mm_P7.62mm_Horizontal

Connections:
+3V3: P1.1, P1.17
+5V: BZ1.1, D1.2, D2.2, J1.1, P1.2, P1.4, P1.8, P1.36, P1.38, P1.40
/GPIO2(SDA1): P1.3, R1.1
/GPIO3(SCL1): P1.5, R2.1
/GPIO12(PWM0): Off On.2, P1.32
/GPIO13(PWM1): J1.2, P1.33
GND: P1.6, P1.9, P1.10, P1.12, P1.14, P1.16, P1.18, P1.20, P1.22, P1.24, P1.25, P1.26, P1.30, P1.34, P1.39
unnamed: BZ1.2, Off On.3
unnamed: D1.1, R1.2
unnamed: D2.1, R2.2

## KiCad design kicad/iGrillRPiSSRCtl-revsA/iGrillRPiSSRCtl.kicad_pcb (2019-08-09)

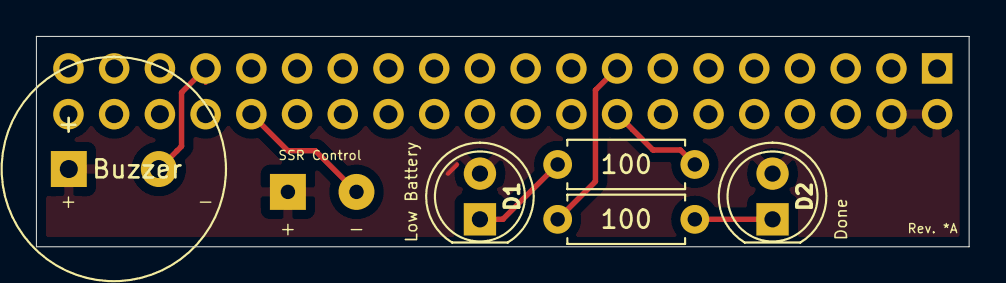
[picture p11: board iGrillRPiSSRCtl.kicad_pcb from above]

Board: 2 copper layers, 51.8 x 11.7 mm, 7 parts (1 on the bottom side), 7 nets.

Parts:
BZ1: Buzzer; Buzzer_TDK_PS1240P02BT_D12.2mm_H6.5mm
D1: Low Battery; LED_D5.0mm
D2: Done; LED_D5.0mm_Clear
J1: Raspberry_Pi_2_3; PinSocket_2x20_P2.54mm_Vertical
J2: SSR Control; SolderWirePad_1x02_P3.81mm_Drill0.8mm
R1, R2: 100; R_Axial_DIN0207_L6.3mm_D2.5mm_P7.62mm_Horizontal

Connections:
+5V: BZ1.1, D1.2, D2.2, J1.2, J1.4, J2.1
unnamed: BZ1.2, J1.33
unnamed: D1.1, R1.2
unnamed: D2.1, R2.2
unnamed: J1.15, R2.1
unnamed: J1.16, R1.1
unnamed: J1.32, J2.2

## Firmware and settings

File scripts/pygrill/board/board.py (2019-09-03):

#!/usr/bin/env python3
"""
  Copyright (c) 2019:   Scott Atkins <scott@kins.dev>
                        (https://git.kins.dev/igrill-smoker)
  License:              MIT License
                        See the LICENSE file
"""

__author__ = "Scott Atkins"
__version__ = "1.4.0"
__license__ = "MIT"


import pigpio
import logging
import argparse
import configparser
import time
import os
# Line to make pylint work
from argparse import ArgumentParser
from ..common.local_logging import SetupLog
from ..common.constant import SSRC, CONFIG


def DetectBoard(board):
    if (SSRC.BOARD.DETECT_REV != board):
        return board
    else:
        pi = pigpio.pi()
        i = 0
        val = 0
        for p in SSRC.BOARD.REV_PINS:
            pi.set_mode(p, pigpio.INPUT)

            pi.set_pull_up_down(p, pigpio.PUD_DOWN)
            tmp = pi.read(p)
            #logging.debug("Pin \"{}\" : \"{}\"".format(p, tmp))
            val = val + (tmp << i)
            i = i + 1
        #logging.debug("Val = \"{}\"".format(val))
        if (val in SSRC.BOARD.REV_MAP):
            return SSRC.BOARD.REV_MAP[val]
        return SSRC.BOARD.DISABLED

def DetectID(board):
    realBoard = DetectBoard(board)
    if(realBoard == SSRC.BOARD.REV_ss):
        return -1
    if(realBoard == SSRC.BOARD.REV_sA):
        return -1
    if(realBoard == SSRC.BOARD.REV_sB):
        return -1
    if(realBoard == SSRC.BOARD.REV_sC):
        return -1
    if(realBoard == SSRC.BOARD.REV_sD):
        return -1
    if(realBoard == SSRC.BOARD.REV_sD_Patched):
        return -1
    pi = pigpio.pi()
    i = 0
    val = 0
    for p in SSRC.BOARD.ID_PINS:
        pi.set_mode(p, pigpio.INPUT)

        pi.set_pull_up_down(p, pigpio.PUD_DOWN)
        tmp = pi.read(p)
        #logging.debug("Pin \"{}\" : \"{}\"".format(p, tmp))
        val = val + (tmp << i)
        i = i + 1
    return val

def main():
    config = configparser.ConfigParser()
    # does not throw an error, just returns the empty set if the file doesn't exist
    config.read(CONFIG.BASEPATH+'/config/iGrill_config.ini')
    loglevel = config.get("Logging", "LogLevel", fallback="Error")
    logfile = config.get("Logging", "LogFile", fallback="")
    board = config.get("SSR", "Board")

    parser = argparse.ArgumentParser(
        description='Sets the leds on the SSR control board')
    parser.add_argument(
        '-l',
        '--log-level',
        action='store',
        dest='log_level',
        default=loglevel,
        help='Set log level, default: \'' + loglevel + '\'')
    parser.add_argument(
        '-d',
        '--log-destination',
        action='store',
        dest='log_destination',
        default=logfile,
        help='Set log destination (file), default: \'' + logfile + '\'')
    parser.add_argument(
        '--id',
        action='store_true',
        dest='id',
        help='Prints the board id')
    options = parser.parse_args()

    SetupLog(options.log_level, options.log_destination)
    if(options.id):
        print(DetectID(board))
    else:
        DetectBoard(board)


if __name__ == '__main__':
    main()

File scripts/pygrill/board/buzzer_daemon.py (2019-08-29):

#!/usr/bin/env python3
"""
  Copyright (c) 2019:   Scott Atkins <scott@kins.dev>
                        (https://git.kins.dev/igrill-smoker)
  License:              MIT License
                        See the LICENSE file
"""

__author__ = "Scott Atkins"
__version__ = "1.4.0"
__license__ = "MIT"

import pigpio
import time
import logging
import argparse
import configparser
import threading
import os
import sys
from Pyro5.api import expose, behavior, Daemon
from ..common.constant import SSRC, BUZZ, CONFIG
from . import board
from struct import pack
from ..common.local_logging import SetupLog


@expose
@behavior(instance_mode="single")
class Buzzer(object):
    def __init__(self, daemon, boardIn="Auto"):
        self.m_daemon = daemon
        config = configparser.ConfigParser()
        # does not throw an error, just returns the empty set if the file doesn't exist
        config.read(CONFIG.BASEPATH+'/config/iGrill_config.ini')
        boardVal = board.DetectBoard(
            config.get("SSR", "Board", fallback=boardIn))
        if (SSRC.BOARD.DISABLED == boardVal):
            sys.exit(1)
        self.m_boardVal = boardVal
        self.m_exitCode = 0
        self.m_lowBattery = False
        self.m_done = False
        self.m_active = True
        self.m_threadCondition = threading.Condition()
        self.m_lock = threading.Lock()
        self.m_thread = threading.Thread(target=self.StartThread, args=())
        self.m_thread.start()

    def StartThread(self):
        logging.debug("Starting thread")
        pi = pigpio.pi()
        item = SSRC.BOARD.ITEMS["Buzzer"][self.m_boardVal]
        onVal = BUZZ.PWM.MAX // 2  # integer division
        if item[SSRC.BOARD.ITEM_VALUE] == SSRC.BOARD.VALUES_STANDARD:
            offVal = BUZZ.PWM.MIN
        else:
            offVal = BUZZ.PWM.MAX
        pin = item[SSRC.BOARD.ITEM_IO]
        loop_cnt = 0
        loop_val = {
            "low battery": {
                1: {
                    "frequency": BUZZ.PWM.FREQ1,
                    "compare": onVal
                },
                0: {
                    "frequency": BUZZ.PWM.FREQ3,
                    "compare": onVal
                }
            },
            "done": {
                1: {
                    "frequency": BUZZ.PWM.FREQ2,
                    "compare": onVal
                },
                0: {
                    "frequency": BUZZ.PWM.FREQ2,
                    "compare": offVal
                }
            },
            "quiet": {
                1: {
                    "frequency": BUZZ.PWM.FREQ1,
                    "compare": offVal
                },
                0: {
                    "frequency": BUZZ.PWM.FREQ1,
                    "compare": offVal
                }
            }
        }
        self.m_threadCondition.acquire()
        while True:
            loop_cnt = loop_cnt + 1
            loop_cnt = loop_cnt % 2
            fun = "quiet"
            with self.m_lock:
                lowBattery = self.m_lowBattery
                done = self.m_done
                active = self.m_active
            if not active:
                pi.hardware_PWM(pin, BUZZ.PWM.FREQ1, offVal)
                break
            if lowBattery:
                logging.debug("Low battery")
                fun = "low battery"
            elif done:
                logging.debug("Done")
                fun = "done"
            else:
                logging.debug("Quiet")
                fun = "quiet"

            pi.hardware_PWM(
                pin, loop_val[fun][loop_cnt]["frequency"], loop_val[fun][loop_cnt]["compare"])
            self.m_threadCondition.wait(0.5)
        self.m_threadCondition.release()

    def Done(self):
        logging.debug("Starting done buzzer")
        with self.m_lock:
            self.m_done = True
            self.m_lowBattery = False
        self.m_threadCondition.acquire()
        self.m_threadCondition.notify()
        self.m_threadCondition.release()

    def LowBattery(self):
        logging.debug("Starting low battery buzzer")
        with self.m_lock:
            self.m_done = False
            self.m_lowBattery = True
        self.m_threadCondition.acquire()
        self.m_threadCondition.notify()
        self.m_threadCondition.release()

    def Stop(self):
        logging.debug("Stopping buzzer")
        with self.m_lock:
            self.m_done = False
            self.m_lowBattery = False
        self.m_threadCondition.acquire()
        self.m_threadCondition.notify()
        self.m_threadCondition.release()

    def ExitCode(self):
        return self.m_exitCode

    def Exit(self):
        with self.m_lock:
            self.m_active = False
        self.m_threadCondition.acquire()
        self.m_threadCondition.notify()
        self.m_threadCondition.release()
        self.m_thread.join()
        logging.debug("Closing socket")
        self.m_daemon.shutdown()


def main():
    config = configparser.ConfigParser()
    # does not throw an error, just returns the empty set if the file doesn't exist
    config.read(CONFIG.BASEPATH+'/config/iGrill_config.ini')
    loglevel = config.get("Logging", "LogLevel", fallback="Error")
    logfile = config.get("Logging", "LogFile", fallback="")

    parser = argparse.ArgumentParser(
        description='Runs a thread to control the buzzer')
    parser.add_argument(
        '-l',
        '--log-level',
        action='store',
        dest='log_level',
        default=loglevel,
        help='Set log level, default: \'' + loglevel + '\'')
    parser.add_argument(
        '-d',
        '--log-destination',
        action='store',
        dest='log_destination',
        default=logfile,
        help='Set log destination (file), default: \'' + logfile + '\'')
    options = parser.parse_args()

    SetupLog(options.log_level, options.log_destination)
    daemon = Daemon(host=BUZZ.DAEMON.PYRO_HOST,
                    port=BUZZ.DAEMON.PYRO_PORT)
    buzzObj = Buzzer(daemon)
    uri = daemon.register(
        buzzObj, objectId=BUZZ.DAEMON.PYRO_OBJECT_ID)
    logging.debug(uri)
    daemon.requestLoop()
    logging.debug('exited requestLoop')
    daemon.shutdown()
    daemon.close()
    logging.debug('daemon closed')
    sys.exit(buzzObj.ExitCode())


if __name__ == "__main__":
    main()

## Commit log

2016-11-05 Replace persistence with print.
2016-11-28 Fix read_temperature() to account for multiple bytes of sensor data.
2016-11-28 Update datadog check to report all 4 probe temperatures.
2019-03-20 Bringing in changes from the prototype
2019-03-22 Added sample highcharts file
2019-03-26 Adding json for webpage, adding keep warm stage
2019-03-27 Added stages Changed meat to food Added user overrides + example
2019-03-28 Fix for stage transition
2019-03-30 Timer based changes
2019-04-11 Adding stage time to the state file
2019-05-06 Changes to allow stages to adjust controls
2019-05-21 todos + fix for probe
2019-06-10 Documentation and LED clearing
2019-06-13 adding socket
2019-06-15 Moving print messages to logging
2019-06-19 Threading prototype
2019-06-25 Adding KiCad Files
    [iGrillRPiSSRCtl.kicad_pcb, iGrillRPiSSRCtl.sch]
2019-06-25 Rev *A changes
    [iGrillRPiSSRCtl.kicad_pcb, iGrillRPiSSRCtl.sch]
2019-06-25 Finishing *A layout
    [iGrillRPiSSRCtl.kicad_pcb]
2019-06-26 Board update for parts
    [iGrillRPiSSRCtl.kicad_pcb, iGrillRPiSSRCtl.sch]
2019-06-26 *B Board Rev
    [iGrillRPiSSRCtl-revSB.kicad_pcb, iGrillRPiSSRCtl-revSB.sch]
2019-06-27 File naming consistency *C Board
    [iGrillRPiSSRCtl-rev-sB.kicad_pcb, iGrillRPiSSRCtl-rev-sB.sch, iGrillRPiSSRCtl-rev-sC.kicad_pcb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]
2019-06-27 Board cleanup
    [iGrillRPiSSRCtl-rev-sC.kicad_pcb]
2019-06-27 Electrical Cleanup of Schematic
    [iGrillRPiSSRCtl-rev-sC.sch]
2019-07-03 Board updates
    [iGrillRPiSSRCtl-rev-sC.kicad_pcb, iGrillRPiSSRCtl-rev-sC.sch]
2019-07-03 footprint update
    [iGrillRPiSSRCtl-rev-sC.kicad_pcb]
2019-07-03 Fixing pinout for RPi PWMs
    [iGrillRPiSSRCtl-rev-sC.kicad_pcb, iGrillRPiSSRCtl-rev-sC.sch]
2019-07-03 Updated design to fix issues from protoype
    [iGrillRPiSSRCtl-rev-sC.kicad_pcb, iGrillRPiSSRCtl-rev-sC.sch]
2019-07-04 Updates from protoype **
    [iGrillRPiSSRCtl-rev-sC.kicad_pcb, iGrillRPiSSRCtl-rev-sC.sch]
2019-07-06 Adding led control code
2019-07-06 LEDs should work now
2019-07-07 Detecting board type
2019-07-07 Board detection
2019-07-07 Adding board detect
2019-07-08 Updating board design
    [iGrillRPiSSRCtl-rev-sC.kicad_pcb, iGrillRPiSSRCtl-rev-sC.sch]
2019-07-08 Adding *D
    [iGrillRPiSSRCtl-rev-sD.kicad_pcb, iGrillRPiSSRCtl-rev-sD.sch]
2019-07-08 Moving to smd devices
    [iGrillRPiSSRCtl-rev-sC.kicad_pcb, iGrillRPiSSRCtl-rev-sC.sch]
2019-07-09 Cleanup and fixes
    [iGrillRPiSSRCtl-rev-sC.kicad_pcb, iGrillRPiSSRCtl-rev-sC.sch]
2019-07-09 Fixing bad merge
    [iGrillRPiSSRCtl-rev-sC.kicad_pcb, iGrillRPiSSRCtl-rev-sC.sch]
2019-07-09 Attempting to get my board made
    [iGrillRPiSSRCtl-rev-sC.kicad_pcb]
2019-07-10 Updated schematic, pcb for board id
    [iGrillRPiSSRCtl-rev-sC.kicad_pcb, iGrillRPiSSRCtl-rev-sC.sch]
2019-07-10 *D changes
    [iGrillRPiSSRCtl-rev-sC.kicad_pcb, iGrillRPiSSRCtl-rev-sC.sch, iGrillRPiSSRCtl-rev-sD.kicad_pcb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]
2019-07-10 *D Complete and sent off
    [iGrillRPiSSRCtl-rev-sD.kicad_pcb, iGrillRPiSSRCtl-rev-sD.sch]
2019-07-11 Started to add *D board to the scripts
2019-07-12 Adding *D board support
2019-07-12 Documenting board types
2019-07-16 adding footprints
2019-07-19 Adding *E
    [iGrillRPiSSRCtl-rev-sE.kicad_pcb, iGrillRPiSSRCtl-rev-sE.sch]
2019-07-25 Moved to python board control
2019-07-27 Board Unittests Working
2019-07-27 Add leds unittest
2019-07-27 Adding buzzer test stub
    [test_buzzer.py]
2019-07-28 Adding board checkout script
2019-07-28 Full LED checkout
2019-07-30 Fixing test, constant cleanup
    [board.py, buzzer_client.py, buzzer_daemon.py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]
2019-07-31 Updating buzzer and design for *e
    [iGrillRPiSSRCtl-rev-sE.kicad_pcb, iGrillRPiSSRCtl-rev-sE.sch]
2019-08-01 Adding patched board
2019-08-01 *E board updates
    [iGrillRPiSSRCtl-rev-sE.kicad_pcb, iGrillRPiSSRCtl-rev-sE.sch]
2019-08-03 *E updates
    [iGrillRPiSSRCtl-rev-sE.kicad_pcb, iGrillRPiSSRCtl-rev-sE.sch]
2019-08-03 Fixing pulldown resistors
    [iGrillRPiSSRCtl-rev-sE.kicad_pcb, iGrillRPiSSRCtl-rev-sE.sch]
2019-08-04 Adding SSR and better thread handling
2019-08-05 Adding script to process gerber files
    [iGrillRPiSSRCtl-rev-sE.kicad_pcb]
2019-08-05 Fixed References
    [iGrillRPiSSRCtl-rev-sE.sch]
2019-08-07 *E updates before production
    [iGrillRPiSSRCtl-rev-sE.kicad_pcb]
2019-08-09 Fix for relay pin
2019-08-09 fixed sys path issues
    [buzzer_daemon.py, ssrc_daemon.py]
2019-08-09 Fix for relay
2019-08-09 Fix for ssrc exit
    [ssrc_daemon.py]
2019-08-10 Fix for minimum SSRC value
    [test_leds.py]
2019-08-10 debug print statements
2019-08-10 Disabling debug print statements
2019-08-15 Added board checkout task, updated host names
2019-08-17 Added how to make a stage
2019-08-19 Update of schedule for current run
2019-08-22 Rewrite of Kasa daemon to prevent network errors
    [buzzer_daemon.py, ssrc_daemon.py]
2019-08-22 Socket shutdown updates
2019-08-23 Adding logging on network error
    [ssrc_client.py]
2019-08-25 changing timeout based on actual network interruption
2019-08-29 Updating stages
2019-08-31 Adding ID to board

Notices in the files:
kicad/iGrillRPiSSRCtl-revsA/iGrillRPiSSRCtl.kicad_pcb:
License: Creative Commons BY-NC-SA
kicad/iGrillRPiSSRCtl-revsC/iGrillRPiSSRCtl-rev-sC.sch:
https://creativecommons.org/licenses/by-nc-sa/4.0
